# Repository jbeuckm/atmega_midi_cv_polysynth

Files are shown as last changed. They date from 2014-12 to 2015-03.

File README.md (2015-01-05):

atmega_midi_cv_polysynth
========================

(This is a new clone of my monosynth MIDI>CV that will be modified for polyphonic productions.)

Uses the Arduino MIDI library to operate four x MCP4822 12-bit DAC with internal voltage reference.

Largely based on http://www.experimentalistsanonymous.com/ve3wwg/doku.php?id=analog_synth_midi

Uses 4922 library from http://www.alhin.de/arduino

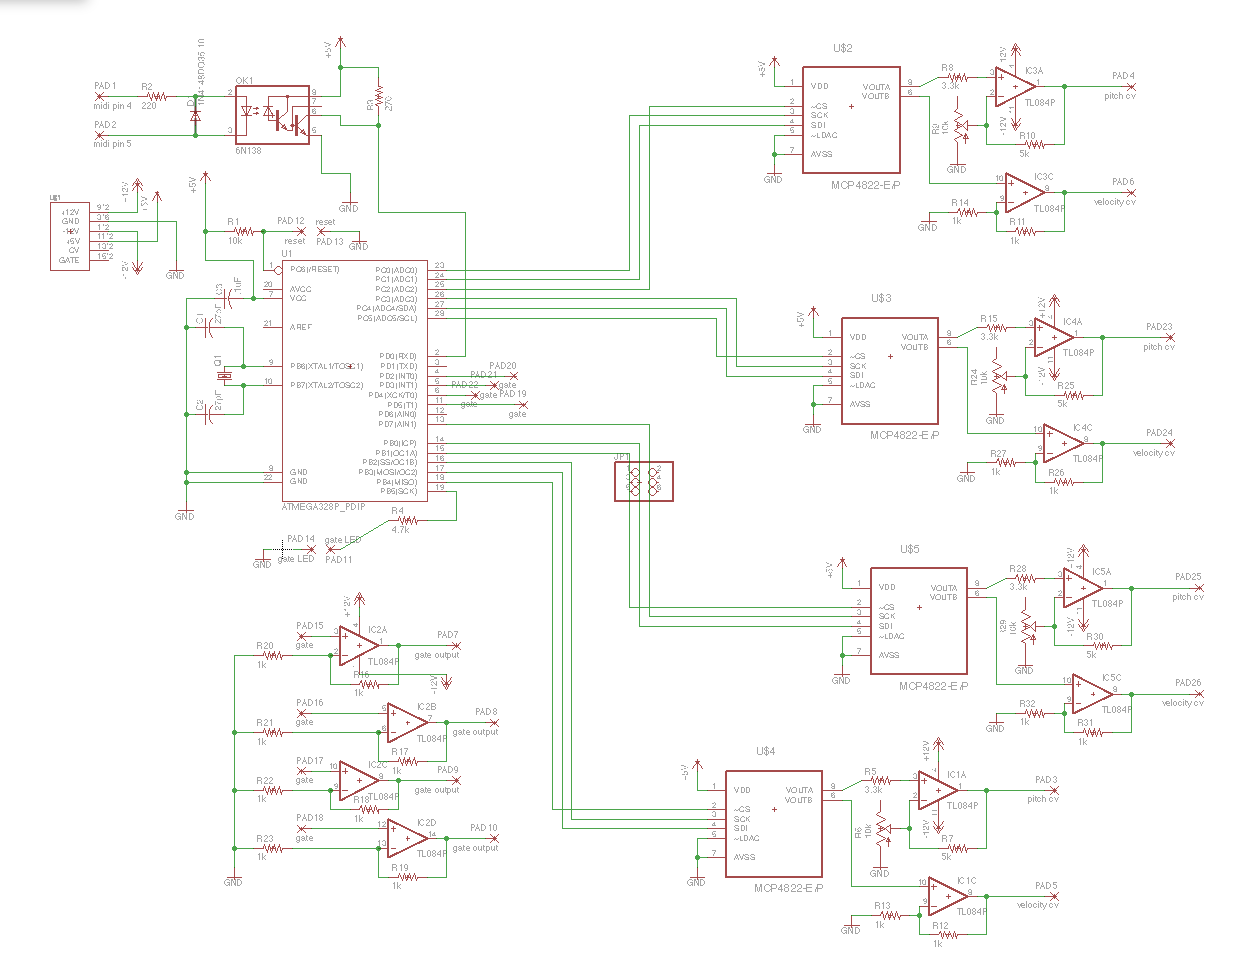
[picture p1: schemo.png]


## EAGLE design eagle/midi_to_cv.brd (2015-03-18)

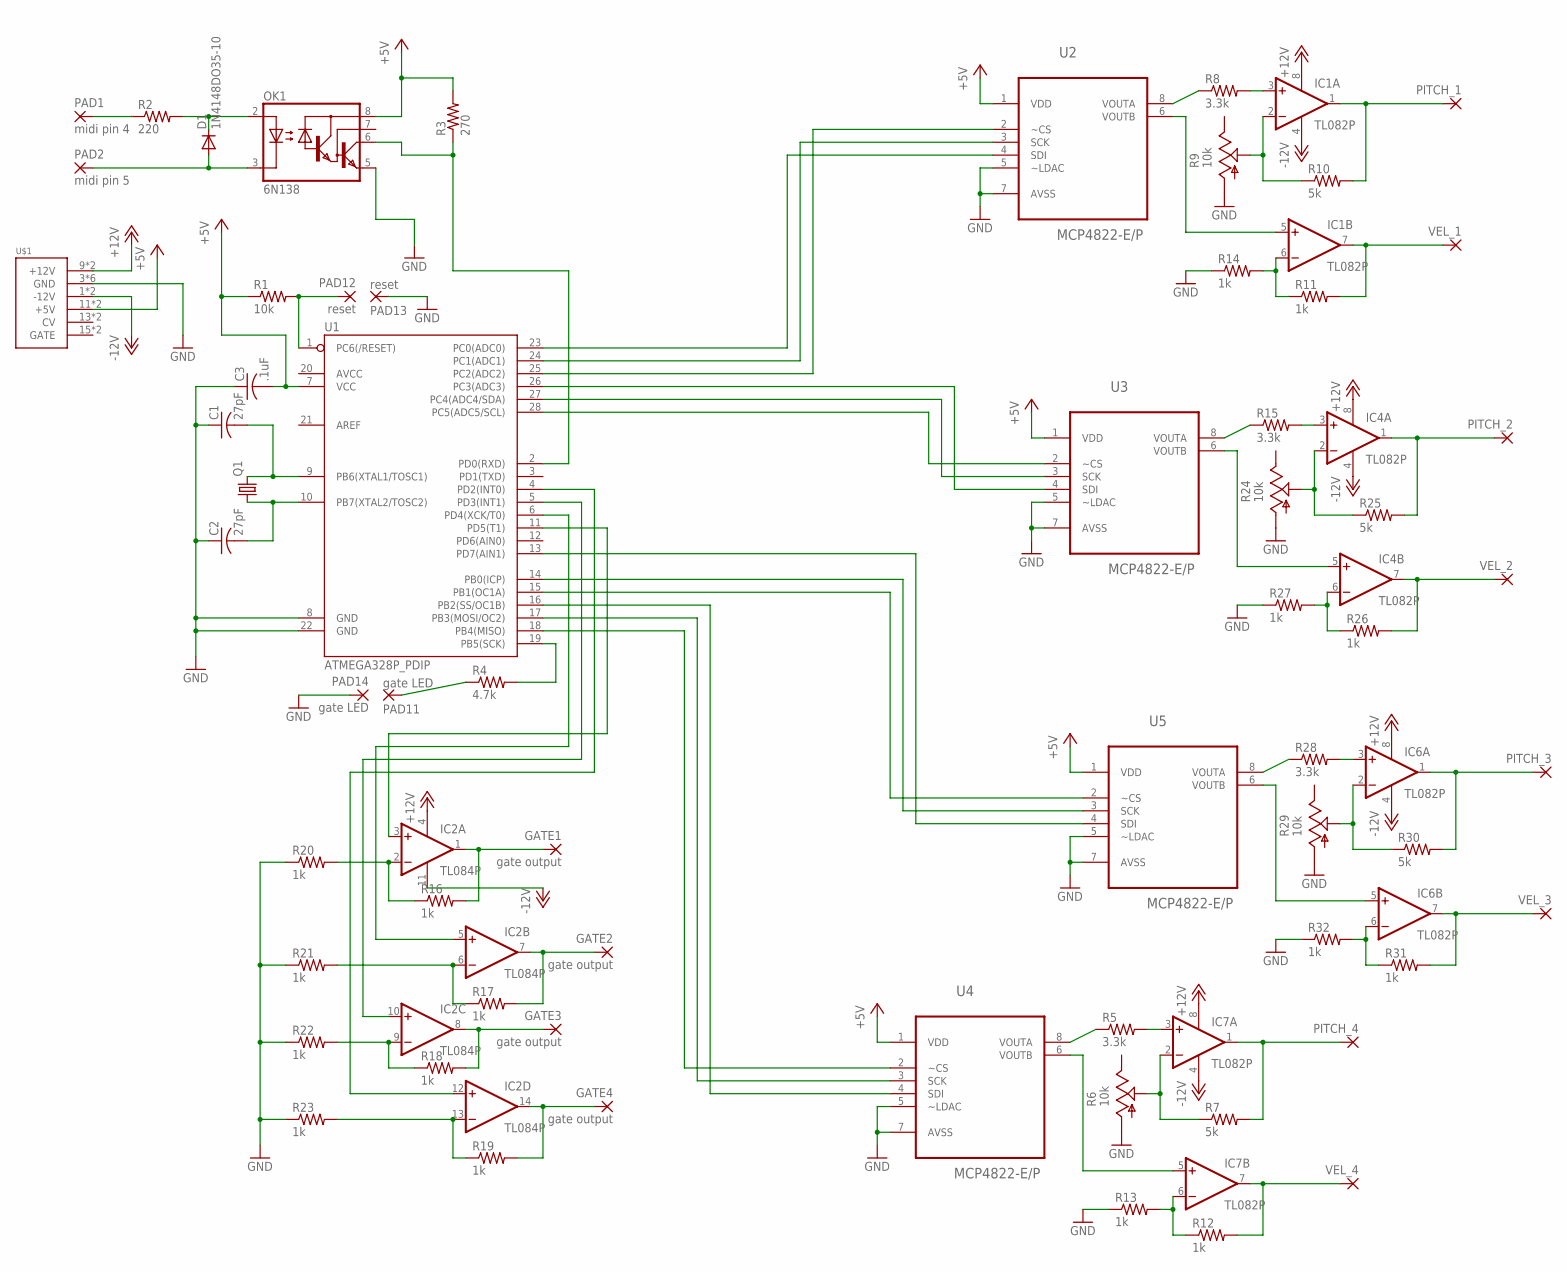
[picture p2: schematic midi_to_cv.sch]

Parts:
C1, C2: 27pF; C025-040X050
C3: .1uF; C025-040X050
D1: 1N4148DO35-10; DO35-10
GATE1, GATE2, GATE3, GATE4: gate output; 2,54/0,9
IC1, IC4, IC6, IC7: TL082P; DIL08
IC2: TL084P; DIL14
OK1: 6N138; DIL08
PAD1: midi pin 4; 2,54/0,9
PAD2: midi pin 5; 2,54/0,9
PAD11, PAD14: gate LED; 2,54/0,9
PAD12, PAD13: reset; 2,54/0,9
PITCH_1, PITCH_2, PITCH_3, PITCH_4: 2,54/0,9
Q1: CRYSTALHC49U-V; HC49U-V
R1: 10k; 0207/10
R2: 220; 0207/10
R3: 270; 0207/10
R4: 4.7k; 0207/10
R5, R8, R15, R28: 3.3k; 0207/10
R6, R9, R24, R29: 10k; B64W
R7, R10, R25, R30: 5k; 0207/10
R11, R12, R13, R14, R16, R17, R18, R19, R20, R21, R22, R23, R26, R27, R31, R32: 1k; 0207/10
U1: ATMEGA328P_PDIP; DIL28-3
U2, U3, U4, U5: MCP4822-E/P; DIP254P762X432-8
U$1: POWER; POWER_16
VEL_1, VEL_2, VEL_3, VEL_4: 2,54/0,9

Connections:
+5V: C3.2, OK1.8 (VCC), R1.1, R3.2, U1.7 (VCC), U2.1 (VDD), U3.1 (VDD), U4.1 (VDD), U5.1 (VDD), U$1.11 (+5V), U$1.12 (+5V)
+12V: IC1.8 (V+), IC2.4 (V+), IC4.8 (V+), IC6.8 (V+), IC7.8 (V+), U$1.9 (+12V), U$1.10 (+12V)
-12V: IC1.4 (V-), IC2.11 (V-), IC4.4 (V-), IC6.4 (V-), IC7.4 (V-), U$1.1 (-12V), U$1.2 (-12V)
GND: C1.1, C2.1, C3.1, OK1.5 (GND), PAD13.1, PAD14.1, R6.A, R9.A, R13.1, R14.1, R20.1, R21.1, R22.1, R23.1, R24.A, R27.1, R29.A, R32.1, U1.8 (GND), U1.22 (GND), U2.5 (~LDAC), U2.7 (AVSS), U3.5 (~LDAC), U3.7 (AVSS), U4.5 (~LDAC), U4.7 (AVSS), U5.5 (~LDAC), U5.7 (AVSS), U$1.3 (GND), U$1.4 (GND), U$1.5 (GND), U$1.6 (GND), U$1.7 (GND), U$1.8 (GND)
unnamed: PAD12.1, R1.2, U1.1 (PC6(/RESET))
unnamed: R5.1, U4.8 (VOUTA)
unnamed: D1.A, OK1.3 (C), PAD2.1
unnamed: C1.2, Q1.2, U1.9 (PB6(XTAL1/TOSC1))
unnamed: C2.2, Q1.1, U1.10 (PB7(XTAL2/TOSC2))
unnamed: IC7.3 (+IN), R5.2
unnamed: D1.C, OK1.2 (A), R2.2
unnamed: PAD1.1, R2.1
unnamed: IC7.1 (OUT), PITCH_4.1, R7.2
unnamed: R4.2, U1.19 (PB5(SCK))
unnamed: PAD11.1, R4.1
unnamed: IC7.2 (-IN), R6.S, R7.1
unnamed: R8.1, U2.8 (VOUTA)
unnamed: U1.17 (PB3(MOSI/OC2)), U4.3 (SCK)
unnamed: U1.16 (PB2(SS/OC1B)), U4.4 (SDI)
unnamed: IC1.3 (+IN), R8.2
unnamed: IC1.1 (OUT), PITCH_1.1, R10.2
unnamed: IC1.2 (-IN), R9.S, R10.1
unnamed: IC7.7 (OUT), R12.2, VEL_4.1
unnamed: IC7.6 (-IN), R12.1, R13.2
unnamed: IC1.7 (OUT), R11.2, VEL_1.1
unnamed: IC1.6 (-IN), R11.1, R14.2
unnamed: IC1.5 (+IN), U2.6 (VOUTB)
unnamed: R15.1, U3.8 (VOUTA)
unnamed: IC4.3 (+IN), R15.2
unnamed: U1.18 (PB4(MISO)), U4.2 (~CS)
unnamed: U1.13 (PD7(AIN1)), U5.4 (SDI)
unnamed: U1.15 (PB1(OC1A)), U5.2 (~CS)
unnamed: OK1.6 (VO), R3.1, U1.2 (PD0(RXD))
unnamed: IC2.3 (+IN), U1.11 (PD5(T1))
unnamed: IC2.5 (+IN), U1.6 (PD4(XCK/T0))
unnamed: GATE1.1, IC2.1 (OUT), R16.2
unnamed: GATE2.1, IC2.7 (OUT), R17.2
unnamed: GATE3.1, IC2.8 (OUT), R18.2
unnamed: GATE4.1, IC2.14 (OUT), R19.2
unnamed: IC2.2 (-IN), R16.1, R20.2
unnamed: IC2.13 (-IN), R19.1, R23.2
unnamed: IC2.9 (-IN), R18.1, R22.2
unnamed: IC2.6 (-IN), R17.1, R21.2
unnamed: IC2.10 (+IN), U1.5 (PD3(INT1))
unnamed: IC2.12 (+IN), U1.4 (PD2(INT0))
unnamed: IC4.1 (OUT), PITCH_2.1, R25.2
unnamed: IC4.2 (-IN), R24.S, R25.1
unnamed: IC7.5 (+IN), U4.6 (VOUTB)
unnamed: IC4.7 (OUT), R26.2, VEL_2.1
unnamed: IC4.6 (-IN), R26.1, R27.2
unnamed: IC4.5 (+IN), U3.6 (VOUTB)
unnamed: R28.1, U5.8 (VOUTA)
unnamed: IC6.3 (+IN), R28.2
unnamed: IC6.1 (OUT), PITCH_3.1, R30.2
unnamed: IC6.2 (-IN), R29.S, R30.1
unnamed: IC6.7 (OUT), R31.2, VEL_3.1
unnamed: IC6.6 (-IN), R31.1, R32.2
unnamed: IC6.5 (+IN), U5.6 (VOUTB)
unnamed: U1.23 (PC0(ADC0)), U2.4 (SDI)
unnamed: U1.24 (PC1(ADC1)), U2.3 (SCK)
unnamed: U1.25 (PC2(ADC2)), U2.2 (~CS)
unnamed: U1.26 (PC3(ADC3)), U3.4 (SDI)
unnamed: U1.27 (PC4(ADC4/SDA)), U3.3 (SCK)
unnamed: U1.28 (PC5(ADC5/SCL)), U3.2 (~CS)
unnamed: U1.14 (PB0(ICP)), U5.3 (SCK)

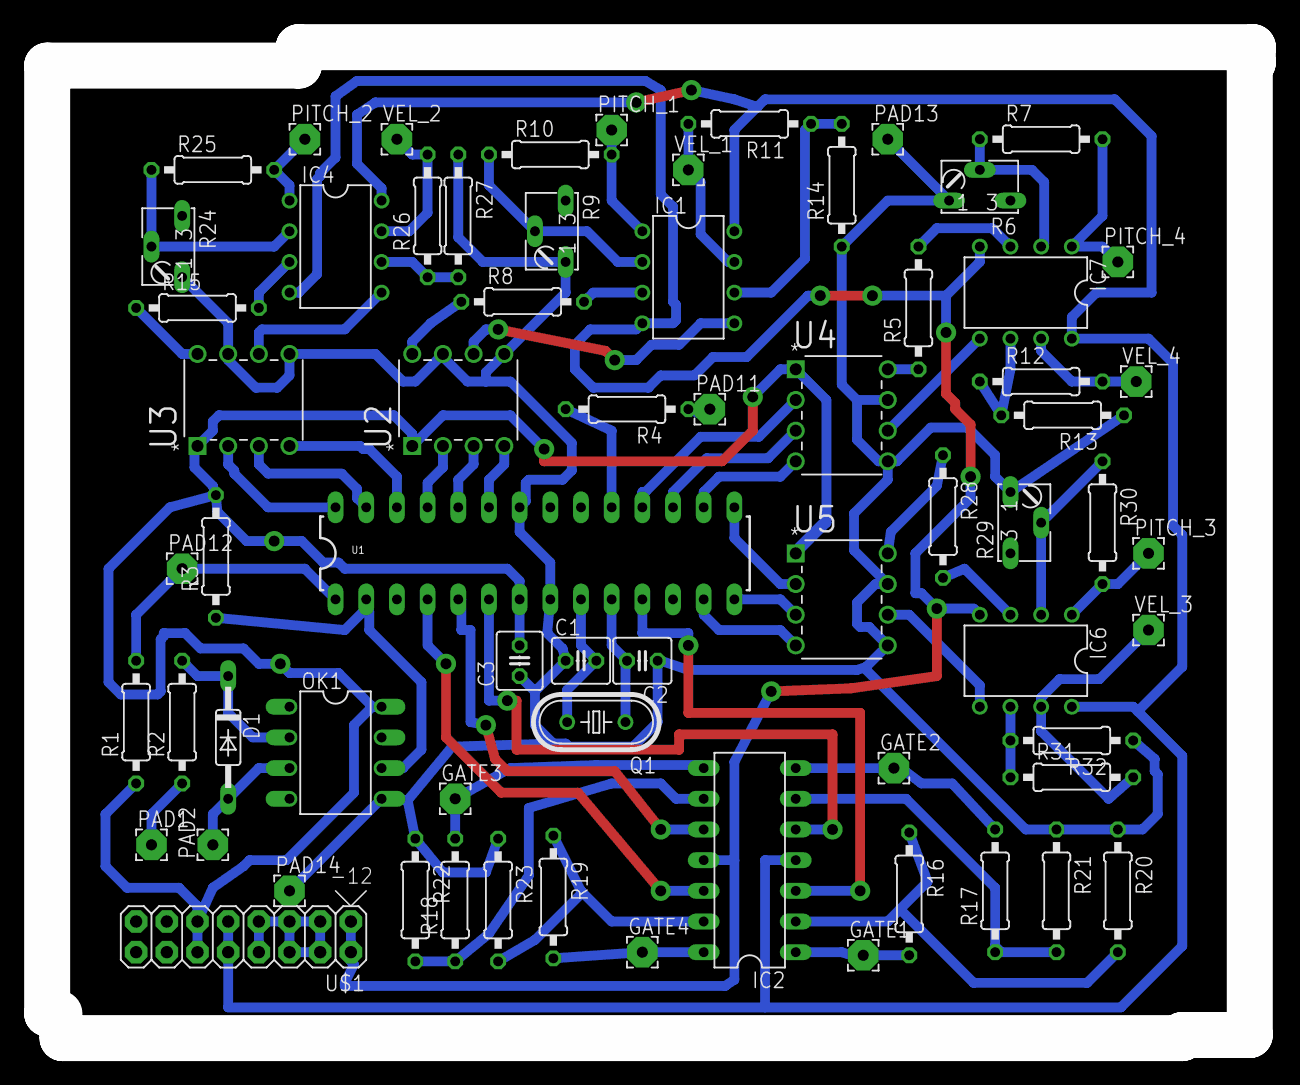
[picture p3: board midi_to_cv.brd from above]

Board: 2 copper layers, 100.1 x 82.0 mm, 67 parts (0 on the bottom side), 65 nets.

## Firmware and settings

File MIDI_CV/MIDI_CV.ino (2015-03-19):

#include <MIDI.h>
#include "AH_MCP4922.h"

//define AnalogOutput (MOSI_pin, SCK_pin, CS_pin, DAC_x, GAIN) 

AH_MCP4922 Pitch1(A0,A1,A2,LOW,LOW);
AH_MCP4922 Velocity1(A0,A1,A2,HIGH,LOW);

AH_MCP4922 Pitch2(A3,A4,A5,LOW,LOW);
AH_MCP4922 Velocity2(A3,A4,A5,HIGH,LOW);

AH_MCP4922 Pitch3(7,8,9,LOW,LOW);
AH_MCP4922 Velocity3(7,8,9,HIGH,LOW);

AH_MCP4922 Pitch4(10,11,12,LOW,LOW);
AH_MCP4922 Velocity4(10,11,12,HIGH,LOW);

AH_MCP4922 pitchDACs[4] = { Pitch1, Pitch2, Pitch3, Pitch4 };
AH_MCP4922 velocityDACs[4] = { Velocity1, Velocity2, Velocity3, Velocity4 };

int gatePins[4] = { 2, 3, 4, 5 };

int noteNumbers[4] = { -1, -1, -1, -1 };  // keep track of notes that have been gated on
int noteBasePitches[4] = { 0, 0, 0, 0 };
int nextNoteOutput = -1;

int pitchbendOffset = 0;

MIDI_CREATE_DEFAULT_INSTANCE();


void handleNoteOn(byte channel, byte pitch, byte velocity)
{
  int i = 0;

  while (i < 4) {

    nextNoteOutput = (nextNoteOutput + 1) % 4;

    if (noteNumbers[nextNoteOutput] == -1) {
      break;
    }

    i++;
  }

  if (i == 4) {
    return;
  }

  noteNumbers[nextNoteOutput] = pitch;

  int basePitch = (pitch - 12) * 42;
  noteBasePitches[nextNoteOutput] = basePitch;  
  pitchDACs[nextNoteOutput].setValue(basePitch + pitchbendOffset);

  velocityDACs[nextNoteOutput].setValue(velocity * 32);

  digitalWrite(gatePins[nextNoteOutput], HIGH);
}

void handleNoteOff(byte channel, byte pitch, byte velocity)
{  

  int i = 0;
  while (i < 4) {
    if (noteNumbers[i] == pitch) {
      digitalWrite(gatePins[i], LOW);
      noteNumbers[i] = -1;
    }
    i++;
  }

}

/*
void handlePitchBend(byte channel, int bend)
 {
 pitchbendOffset = bend / 4;
 
 pitchDACs[0].setValue(noteBasePitches[0] + pitchbendOffset);
 pitchDACs[1].setValue(noteBasePitches[1] + pitchbendOffset);
 pitchDACs[2].setValue(noteBasePitches[2] + pitchbendOffset);
 pitchDACs[3].setValue(noteBasePitches[3] + pitchbendOffset);
 }
 */

// -----------------------------------------------------------------------------

void setup()
{

  pinMode(A0, OUTPUT);
  pinMode(A1, OUTPUT);
  pinMode(A2, OUTPUT);
  pinMode(A3, OUTPUT);
  pinMode(A4, OUTPUT);
  pinMode(A5, OUTPUT);

  pinMode(gatePins[0], OUTPUT);
  pinMode(gatePins[1], OUTPUT);
  pinMode(gatePins[2], OUTPUT);
  pinMode(gatePins[3], OUTPUT);

  pinMode(7, OUTPUT);
  pinMode(8, OUTPUT);
  pinMode(9, OUTPUT);
  pinMode(10, OUTPUT);
  pinMode(11, OUTPUT);
  pinMode(12, OUTPUT);


  MIDI.setHandleNoteOn(handleNoteOn);
  MIDI.setHandleNoteOff(handleNoteOff);

  //  MIDI.setHandlePitchBend(handlePitchBend);

  MIDI.begin(4);

  // C8 at full velocity for 8.0V calibration on powerup
  handleNoteOn(4, 108, 127);
  handleNoteOn(4, 108, 127);
  handleNoteOn(4, 108, 127);
  handleNoteOn(4, 108, 127);

  noteNumbers[0] = -1;
  noteNumbers[1] = -1;
  noteNumbers[2] = -1;
  noteNumbers[3] = -1;

  pinMode(13, OUTPUT);
  digitalWrite(13, LOW);
}

void loop()
{
  MIDI.read();
}

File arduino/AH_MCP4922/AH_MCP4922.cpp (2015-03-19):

/*************************************************************************
**  Device: MCP4922                                                 	**
**  File:   AH_MCP4922.h - Library for get out analog voltage          	**
**								    	**
**  Created by A. Hinkel 2011-12-28  					**
**  download from "http://www.alhin.de/arduino"  			**
**					                               	**
**  Based on code from:							**
**  http://www.sinneb.net/2010/06/mcp4922-12bit-dac-voltage-controller/ **
**									**
**  Released into the public domain.  		                    	**
**                                                                  	**
**                                                                  	**
**************************************************************************/


#if defined(ARDUINO) && ARDUINO >= 100
#include "Arduino.h"
#else
#include "WProgram.h"
#endif

#include "AH_MCP4922.h"


AH_MCP4922::AH_MCP4922(int SDI, int SCK, int CS, boolean DAC, boolean GAIN)
{
 _DATAOUT = SDI;
 _SPICLOCK = SCK;
 _SLAVESELECT = CS;
 _DAC = DAC;
 _GAIN = GAIN;

 pinMode(_DATAOUT,OUTPUT);
 pinMode(_SPICLOCK,OUTPUT);
 pinMode(_SLAVESELECT,OUTPUT);

}

//************************************************************************
void AH_MCP4922::setValue(int Value) {
  sendIntValueSPI(Value);
}
//************************************************************************ 
void AH_MCP4922::sendSPIClock() {
  digitalWrite(_SPICLOCK, HIGH);
  digitalWrite(_SPICLOCK, LOW);
//  delay(1);
  delayMicroseconds(1);
}

//************************************************************************ 
void AH_MCP4922::sendSPIHeader() {
  					// bit 15
					// 0 write to DAC_A 
					// 1 write to DAC_B
  digitalWrite(_DATAOUT,_DAC);
  sendSPIClock();
					// bit 14 Vref input buffer control
					// 0 unbuffered
					// 1 buffered
  digitalWrite(_DATAOUT,LOW);
  sendSPIClock();
					// bit 13 Output Gain selection
					// 0 2x
					// 1 1x
  digitalWrite(_DATAOUT,_GAIN);
  sendSPIClock();
					// bit 12 Output shutdown control bit
					// 0 Shutdown the device
					// 1 Active mode operation *
  digitalWrite(_DATAOUT,HIGH);
  sendSPIClock();
}
 
//************************************************************************
void AH_MCP4922::sendIntValueSPI(int value) {
 // initiate data transfer with 4922
 digitalWrite(_SLAVESELECT,LOW);
 
 // send 4 bit header
 sendSPIHeader();
 
  // send data
  for(int i=11;i>=0;i--){
    digitalWrite(_DATAOUT,((value&(1<<i)))>>i);
    sendSPIClock();
  }
 
  // finish data transfer
  digitalWrite(_SLAVESELECT,HIGH);
} 
 
 

 

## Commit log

2014-12-19 initial commit of cloned repo
    [midi_to_cv.brd, midi_to_cv.sch]
2014-12-21 converting to poly4
    [midi_to_cv.brd, midi_to_cv.sch]
2014-12-21 replicated pitch and velocity outputs four times
    [midi_to_cv.brd, midi_to_cv.sch]
2014-12-21 connected the dacs
    [midi_to_cv.brd, midi_to_cv.sch]
2014-12-21 prettied up the schematic
    [midi_to_cv.brd, midi_to_cv.sch]
2014-12-21 renumbered op amps
    [midi_to_cv.brd, midi_to_cv.sch]
2014-12-22 moved parts onto board area
    [midi_to_cv.brd, midi_to_cv.sch]
2014-12-23 working to route the board
    [midi_to_cv.brd, midi_to_cv.sch]
2014-12-23 swapped dac control lines and need to do so in software
    [midi_to_cv.brd, midi_to_cv.sch]
2014-12-23 nearly routable
    [midi_to_cv.brd]
2014-12-24 hand routing
    [midi_to_cv.brd]
2014-12-24 manually routed and vias adjusted
    [midi_to_cv.brd]
2014-12-25 will route gates to op amps instead of jumper pads
    [midi_to_cv.brd, midi_to_cv.sch]
2014-12-25 routed with vias to gates
    [midi_to_cv.brd, midi_to_cv.sch]
2015-01-05 corrected dac com lines for the updated schematic and things work
    [midi_to_cv.brd]
2015-03-18 updated arduino code
    [midi_to_cv.brd, midi_to_cv.sch]

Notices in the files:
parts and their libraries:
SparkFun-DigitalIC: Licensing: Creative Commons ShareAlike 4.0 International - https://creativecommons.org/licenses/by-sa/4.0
